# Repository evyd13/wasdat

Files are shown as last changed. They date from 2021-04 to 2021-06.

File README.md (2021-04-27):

# Wasdat and Wasdat Code
The Wasdat and Wasdat Code are are replacement controllers for the WASD V2 and WASD CODE V2B, respectively.

# Use KiCAD nightly!
If you have any trouble opening these files, please download and install the lastest nightly build of KiCAD.

# Read the license!
As with all my projects, please read the license before using these files.

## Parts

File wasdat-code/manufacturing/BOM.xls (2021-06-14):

Wasdat Code BOM
Manufacturer | Manufacturer Part Number | Designator | Qty | Description | Case | SMD ,BGA,LCC,OR TH | Top/Bottom | points (number of contacts the IC has in each board) | Total points (number of contacts per BOM line has) | Comment
Samsung Electro-Mechanics | CL10B104KO8NNNC | C1, C2, C3 | 3 | 100nf capacitor | 0603 | SMD | Bottom
Samsung Electro-Mechanics | CL21A475KAQNNNE | C4 | 1 | 4.7uf capacitor | 0603 | SMD | Bottom
Samsung Electro-Mechanics | CL10A105KP8NNNC | C5 | 1 | 1uf capacitor | 0603 | SMD | Bottom
TLC Electronic | TLC-PSMD050 | F1 | 1 | PTC fuse | 0805 | SMD | Bottom
 |  | H1, H2 | 2 | 2x12 male pin header 2.00mm pitch |  | TH | Bottom
Walsin Tech Corp | WR06X220JTL | R1, R2 | 2 | 22 ohm resistor | 0603 | SMD | Bottom
Walsin Tech Corp | WR06X103JTL | R3, R4, R5 | 2 | 10k ohm resistor | 0603 | SMD | Bottom
Walsin Tech Corp | WR06X102 JTL | R6, R7, R8 | 3 | 1k ohm resistor | 0603 | SMD | Bottom
PANASONIC | ERJP06J750V | R9-R16 | 8 | 75 ohm resistor | 0805 | SMD | Bottom
Microchip Tech | ATMEGA32U4-AU | U1 | 1 | Microcontroller | TQFP-44 | SMD | Bottom
Murata Electronics | CSTNE16M0V530000R0 | X1 | 1 | Resonator 16mhz |  | SMD | Bottom
 | AO3400 | Q1 | 1 | N channel MOSFET | SOT-23 | SMD | Top
Nexperia | 74HC138D | U2 | 1 | Demultiplexer 3-8 line active low | SOIC-16 3.9x9.9 P1.27mm | SMD | Top

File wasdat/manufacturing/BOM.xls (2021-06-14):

Wasdat BOM
Manufacturer | Manufacturer Part Number | Designator | Qty | Description | Case | SMD ,BGA,LCC,OR TH | Top/Bottom | points (number of contacts the IC has in each board) | Total points (number of contacts per BOM line has) | Comment
Samsung Electro-Mechanics | CL10B104KO8NNNC | C1-C4 | 4 | 100nf capacitor | 0603 | SMD | Bottom
Samsung Electro-Mechanics | CL21A475KAQNNNE | C5 | 1 | 4.7uf capacitor | 0805 | SMD | Bottom
Samsung Electro-Mechanics | CL10A105KP8NNNC | C5 | 1 | 1uf capacitor | 0603 | SMD | Bottom
TLC Electronic | TLC-PSMD050 | F1 | 1 | PTC fuse | 0805 | SMD | Bottom
 |  | H1, H2 | 2 | 2x13 male pin header 2.00mm pitch |  | TH | Bottom
Walsin Tech Corp | WR06X220JTL | R1, R2 | 2 | 22 ohm resistor | 0603 | SMD | Bottom
Walsin Tech Corp | WR06X103JTL | R3, R4 | 2 | 10k ohm resistor | 0603 | SMD | Bottom
Walsin Tech Corp | WR06X102 JTL | R5, R6, R7 | 3 | 1k ohm resistor | 0603 | SMD | Bottom
Microchip Tech | ATMEGA32U4-AU | U1 | 1 | Microcontroller | TQFP-44 | SMD | Bottom
Murata Electronics | CSTNE16M0V530000R0 | X1 | 1 | Resonator 16mhz |  | SMD | Bottom
Nexperia | 74HC138D | U2 | 1 | Demultiplexer 3-8 line active low | SOIC-16 3.9x9.9 P1.27mm | SMD | Top

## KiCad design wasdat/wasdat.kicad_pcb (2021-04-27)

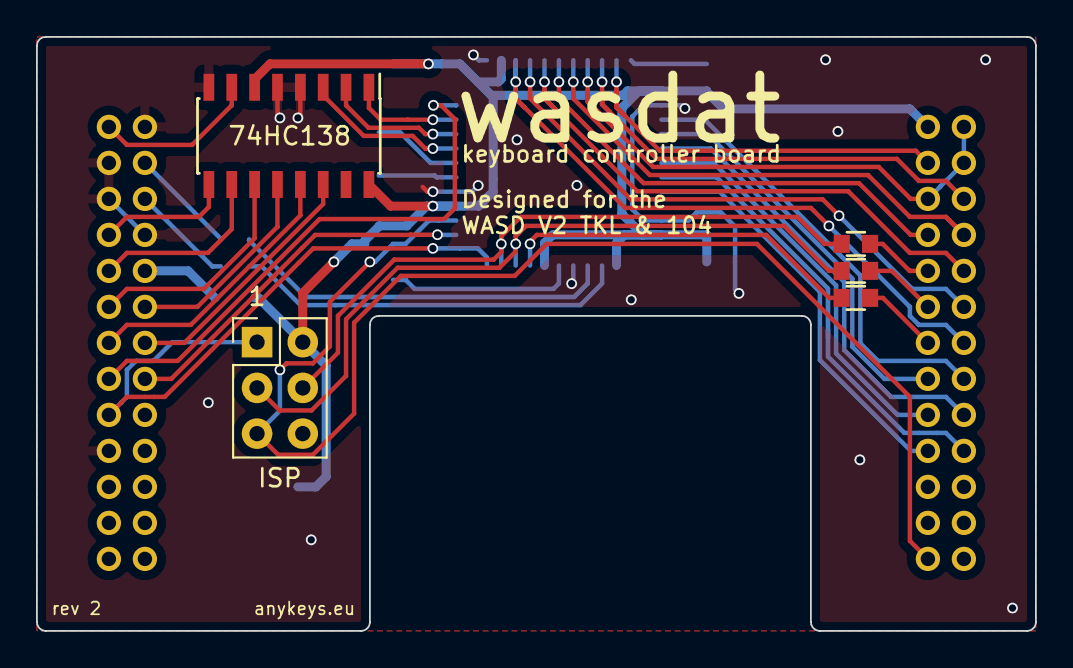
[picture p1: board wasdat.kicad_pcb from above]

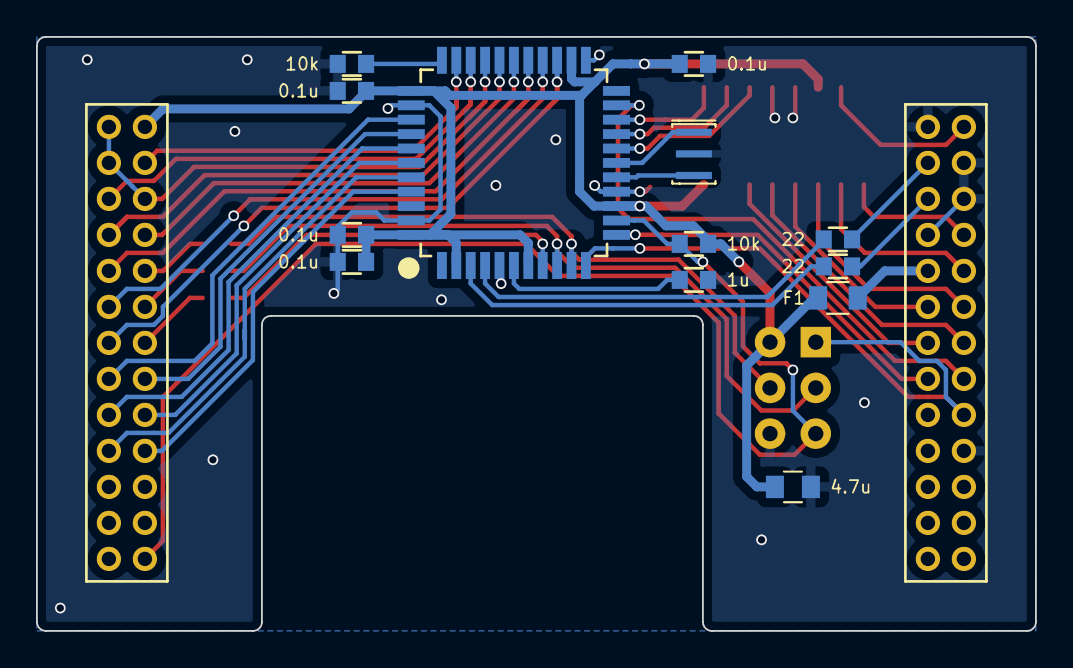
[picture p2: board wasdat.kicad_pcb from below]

Board: 2 copper layers, 55.5 x 33.0 mm, 20 parts (13 on the bottom side), 45 nets.

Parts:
C1, C2, C3, C4: 0.1u; C_0603
C5: 4.7u; C_0805
C6: 1u; C_0603
F1: Polyfuse_Small; R_0805
H1: Left; PinHeader_2x13_P2.00mm_Vertical
H2: Right; PinHeader_2x13_P2.00mm_Vertical
J1: ISP; isp_standard
R1, R2: 22; R_0603
R3, R4: 10k; R_0603
R5, R6, R7: 1k; R_0603
U1: ATmega32U4; ATMEGA32U4
U2: 74HC138; SOIC-16_3.9x9.9mm_P1.27mm
X1: 16mhz; Resonator_SMD_muRata_CSTNExxV-3Pin-p1.2

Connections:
A0: U1.20 ((RXD/INT2)PD2), U2.1 (A0)
A1: U1.19 ((SDA/INT1)PD1), U2.2 (A1)
A2: U1.18 ((OC0B/SCL/INT0)PD0), U2.3 (A2)
D+: H1.4, R1.2
D-: H1.6, R2.2
DIP_1: H2.25, J1.5, R3.2, U1.13 (RESET)
GND: C1.2, C2.2, C3.2, C4.2, C5.2, C6.2, H1.2, H1.3, H1.5, H1.8, H1.19, J1.6, R4.2, U1.5 (UGND), U1.15 (GND), U1.23 (GND), U1.35 (GND), U1.43 (GND), U2.4 (~GL), U2.5 (~G2), U2.8 (GND), X1.3
LED_caps: R7.2, U1.8 ((SS/PCINT0)PB0)
LED_num: J1.4, R5.2, U1.10 ((PDI/MOSI/PCINT2)PB2)
LED_scroll: J1.3, R6.2, U1.9 ((SCLK/PCINT1)PB1)
MISO: H1.17, J1.1, U1.11 ((PDO/MISO/PCINT3)PB3)
unnamed: C6.1, U1.6 (UCAP)
unnamed: F1.2, H1.10
unnamed: H2.9, R5.1
unnamed: H2.11, R6.1
unnamed: H2.13, R7.1
unnamed: R1.1, U1.4 (D+)
unnamed: R2.1, U1.3 (D-)
unnamed: R4.1, U1.33 ((~HWB~)PE2)
unnamed: U1.16 (XTAL2), X1.2
unnamed: U1.17 (XTAL1), X1.1
VCC: C1.1, C2.1, C3.1, C4.1, C5.1, F1.1, H2.1, J1.2, R3.1, U1.2 (UVCC), U1.7 (VBUS), U1.14 (VCC), U1.24 (AVCC), U1.34 (VCC), U1.44 (AVCC), U2.6 (G1), U2.16 (VCC)
col0: H2.3, U1.32 ((ICP3/CLK0/OC4A)PC7)
col1: H2.2, H2.4, H2.5, U1.30 ((ADC13/OC1B/OC4B/PCINT13)PB6)
col2: H2.6, U1.31 ((OC3A/~OC4A~)PC6)
col3: H2.7, U1.28 ((ADC11/PCINT4)PB4)
col4: H2.8, U1.29 ((ADC12/OC1A/~OC4B~/PCINT12)PB5)
col5: H2.10, U1.27 ((T0/OC4D/ADC10)PD7)
col6: H1.1, U2.7 (Y7)
col7: H1.7, U2.9 (Y6)
col8: H1.9, U2.10 (Y5)
col9: H1.11, U2.11 (Y4)
col10: H1.12, U2.12 (Y3)
col11: H1.13, U2.13 (Y2)
col12: H1.14, U2.14 (Y1)
col13: H1.15, U1.21 ((TXD/INT3)PD3)
col14: H1.16, U1.12 ((OC0A/OC1C/~RTS~/PCINT7)PB7)
row0: H2.12, U1.26 ((T1/~OC4D~/ADC9)PD6)
row1: H2.14, U1.25 ((ICP2/ADC8)PD4)
row2: H2.15, U1.37 ((ADC6/TDO)PF6)
row3: H2.16, U1.36 ((ADC7/TDI)PF7)
row4: H2.17, U1.39 ((ADC4/TCK)PF4)
row5: H2.18, U1.38 ((ADC5/TMS)PF5)
row6: H2.19, U1.41 ((ADC0)PF0)
row7: H2.20, U1.40 ((ADC1)PF1)

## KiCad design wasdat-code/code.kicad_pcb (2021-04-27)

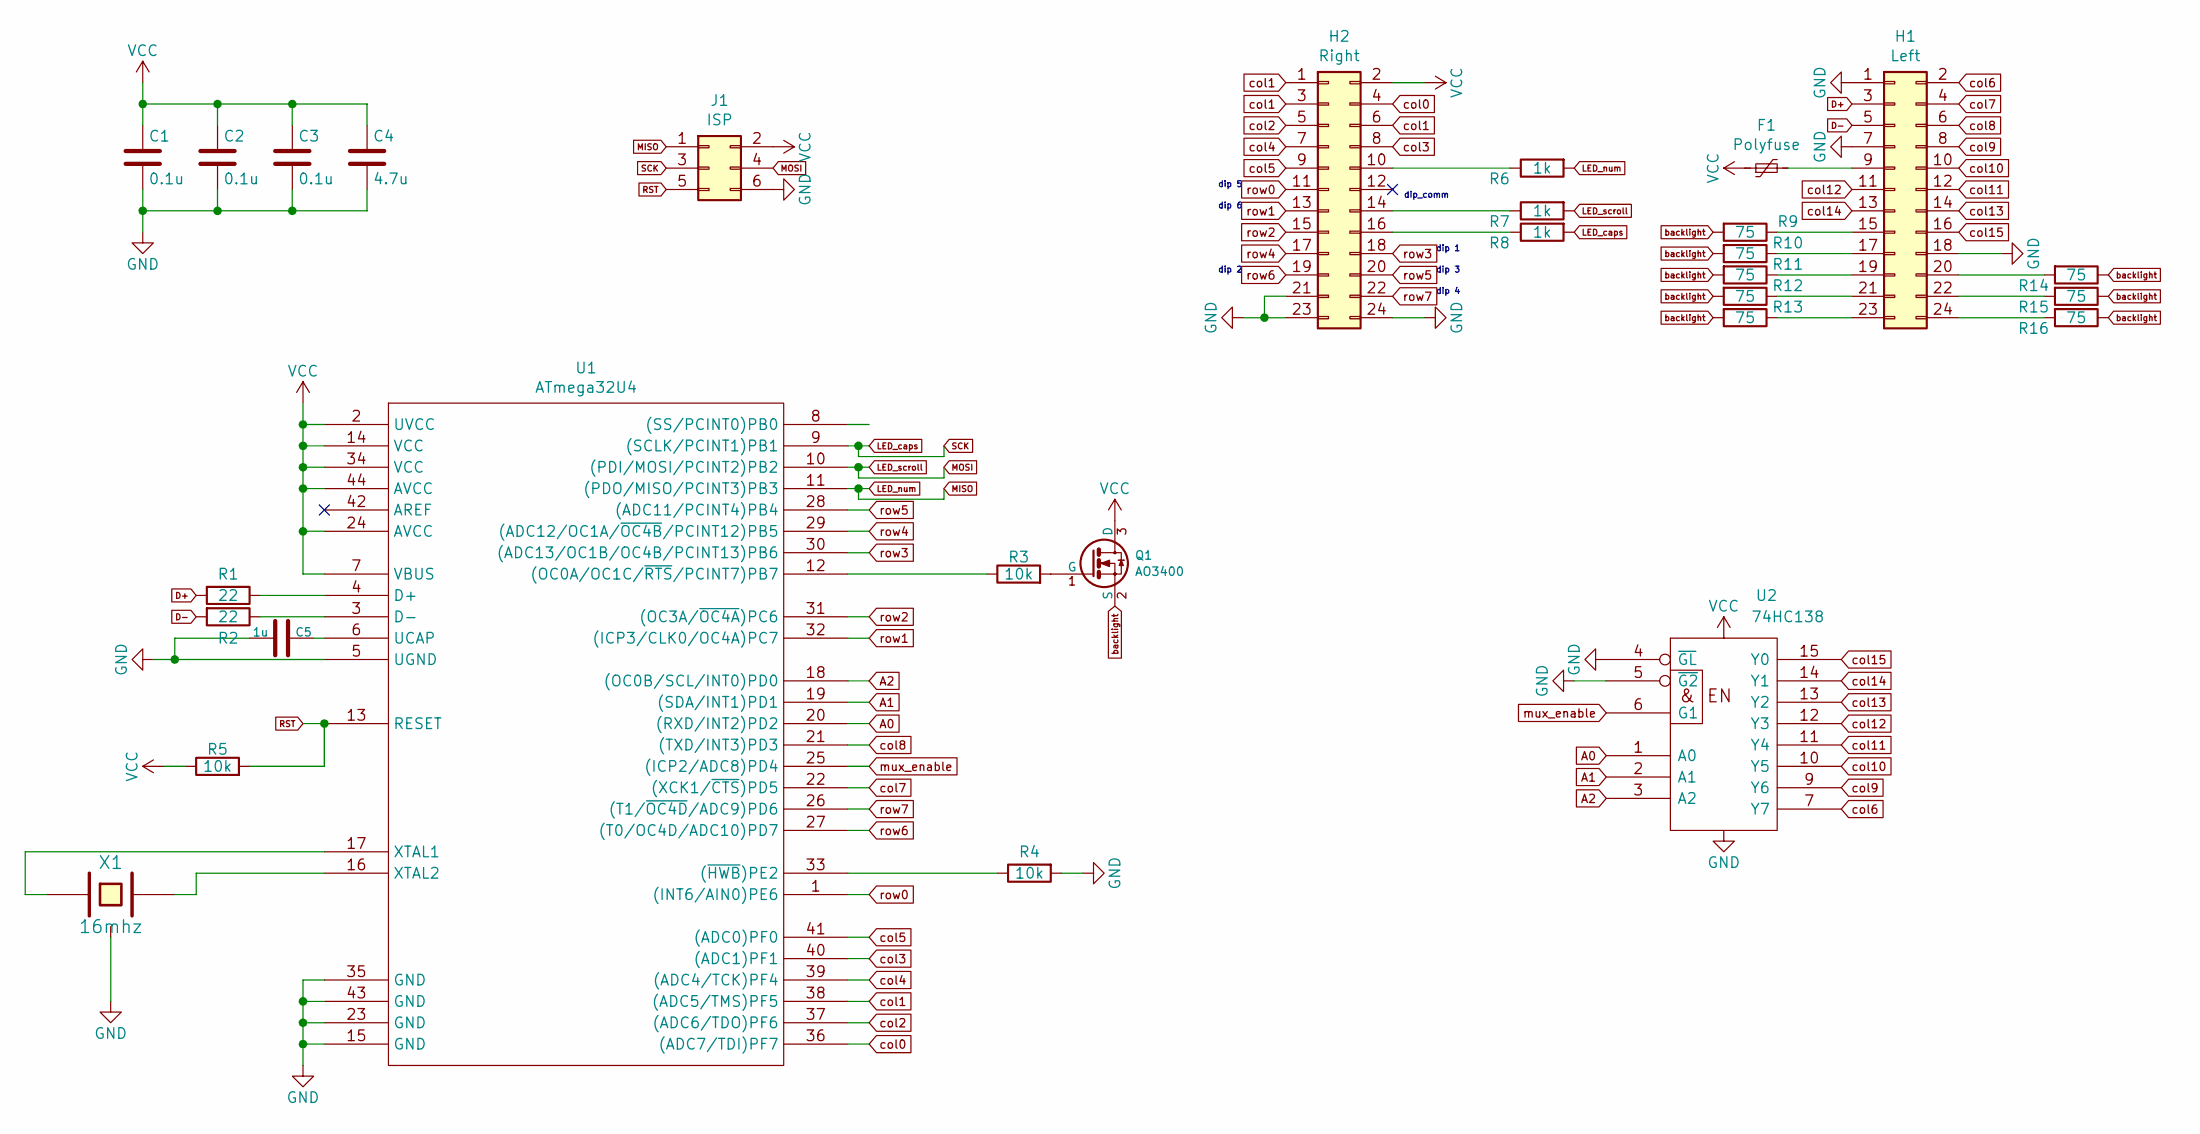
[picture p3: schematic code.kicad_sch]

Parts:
C1, C2, C3: 0.1u; C_0603
C4: 4.7u; C_0805
C5: 1u; C_0603
F1: Polyfuse; R_0805
H1: Left; PinHeader_2x12_P2.00mm_Vertical
H2: Right; PinHeader_2x12_P2.00mm_Vertical
J1: ISP; isp_standard
Q1: AO3400; SOT-23
R1, R2: 22; R_0603
R3, R4, R5: 10k; R_0603
R6, R7, R8: 1k; R_0603
R9, R10, R11, R12, R13, R14, R15, R16: 75; R_0805
U1: ATmega32U4; ATMEGA32U4
U2: 74HC138; SOIC-16_3.9x9.9mm_P1.27mm
X1: 16mhz; Resonator_SMD_muRata_CSTNExxV-3Pin-p1.2

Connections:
A0: U1.20 ((RXD/INT2)PD2), U2.1 (A0)
A1: U1.19 ((SDA/INT1)PD1), U2.2 (A1)
A2: U1.18 ((OC0B/SCL/INT0)PD0), U2.3 (A2)
D+: H1.3, R1.2
D-: H1.5, R2.2
GND: C1.2, C2.2, C3.2, C4.2, C5.2, H1.1, H1.7, H1.18, H2.21, H2.23, H2.24, J1.6, R4.2, U1.5 (UGND), U1.15 (GND), U1.23 (GND), U1.35 (GND), U1.43 (GND), U2.4 (~GL), U2.5 (~G2), U2.8 (GND), X1.3
LED_caps: J1.3, R8.2, U1.9 ((SCLK/PCINT1)PB1)
LED_num: J1.1, R6.2, U1.11 ((PDO/MISO/PCINT3)PB3)
LED_scroll: J1.4, R7.2, U1.10 ((PDI/MOSI/PCINT2)PB2)
unnamed: F1.2, H1.9
unnamed: H1.15, R9.1
unnamed: H1.17, R10.1
unnamed: H1.19, R11.1
unnamed: H1.20, R14.2
unnamed: H1.21, R12.1
unnamed: H1.22, R15.2
unnamed: H1.23, R13.1
unnamed: H1.24, R16.2
unnamed: H2.10, R6.1
unnamed: H2.14, R7.1
unnamed: H2.16, R8.1
unnamed: Q1.1 (G), R3.2
unnamed: R2.1, U1.3 (D-)
unnamed: R3.1, U1.12 ((OC0A/OC1C/~RTS~/PCINT7)PB7)
unnamed: R4.1, U1.33 ((~HWB~)PE2)
unnamed: U1.16 (XTAL2), X1.2
unnamed: U1.17 (XTAL1), X1.1
RST: J1.5, R5.2, U1.13 (RESET)
VCC: C1.1, C2.1, C3.1, C4.1, F1.1, H2.2, J1.2, Q1.3 (D), R5.1, U1.2 (UVCC), U1.7 (VBUS), U1.14 (VCC), U1.24 (AVCC), U1.34 (VCC), U1.44 (AVCC), U2.16 (VCC)
backlight: Q1.2 (S), R9.2, R10.2, R11.2, R12.2, R13.2, R14.1, R15.1, R16.1
col0: H2.4, U1.36 ((ADC7/TDI)PF7)
col1: H2.1, H2.3, H2.6, U1.38 ((ADC5/TMS)PF5)
col2: H2.5, U1.37 ((ADC6/TDO)PF6)
col3: H2.8, U1.40 ((ADC1)PF1)
col4: H2.7, U1.39 ((ADC4/TCK)PF4)
col5: H2.9, U1.41 ((ADC0)PF0)
col6: H1.2, U2.7 (Y7)
col7: H1.4, U1.22 ((XCK1/~CTS~)PD5)
col8: H1.6, U1.21 ((TXD/INT3)PD3)
col9: H1.8, U2.9 (Y6)
col10: H1.10, U2.10 (Y5)
col11: H1.12, U2.11 (Y4)
col12: H1.11, U2.12 (Y3)
col13: H1.14, U2.13 (Y2)
col14: H1.13, U2.14 (Y1)
col15: H1.16, U2.15 (Y0)
mux_enable: U1.25 ((ICP2/ADC8)PD4), U2.6 (G1)
row0: H2.11, U1.1 ((INT6/AIN0)PE6)
row1: H2.13, U1.32 ((ICP3/CLK0/OC4A)PC7)
row2: H2.15, U1.31 ((OC3A/~OC4A~)PC6)
row3: H2.18, U1.30 ((ADC13/OC1B/OC4B/PCINT13)PB6)
row4: H2.17, U1.29 ((ADC12/OC1A/~OC4B~/PCINT12)PB5)
row5: H2.20, U1.28 ((ADC11/PCINT4)PB4)
row6: H2.19, U1.27 ((T0/OC4D/ADC10)PD7)
row7: H2.22, U1.26 ((T1/~OC4D~/ADC9)PD6)

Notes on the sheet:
dip 5
dip 6
dip 2
dip_comm
dip 1
dip 3
dip 4

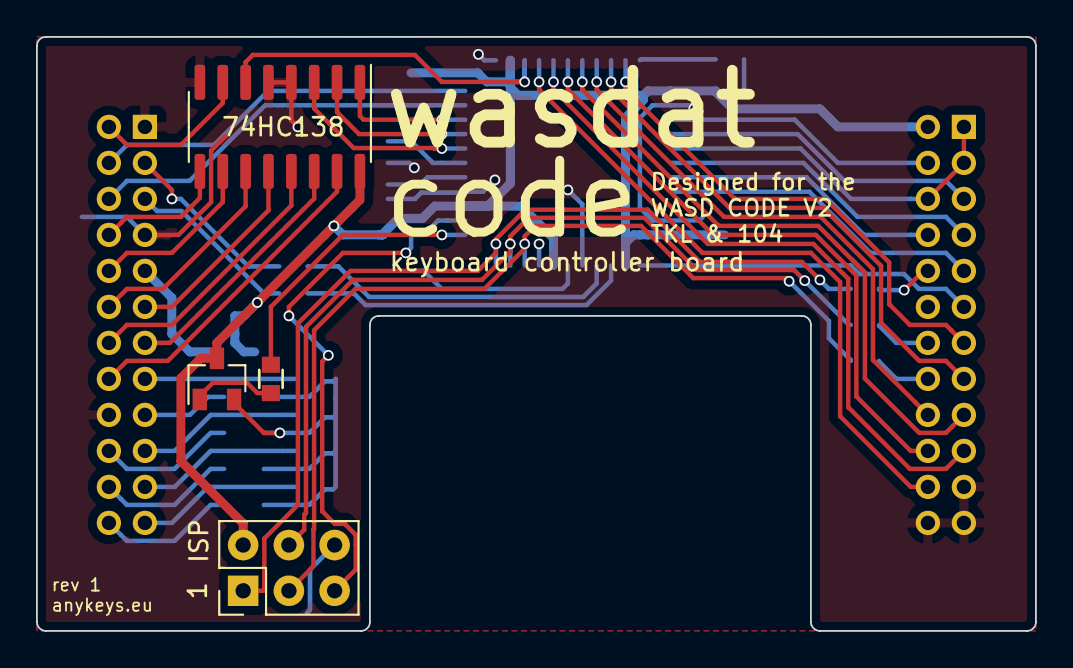
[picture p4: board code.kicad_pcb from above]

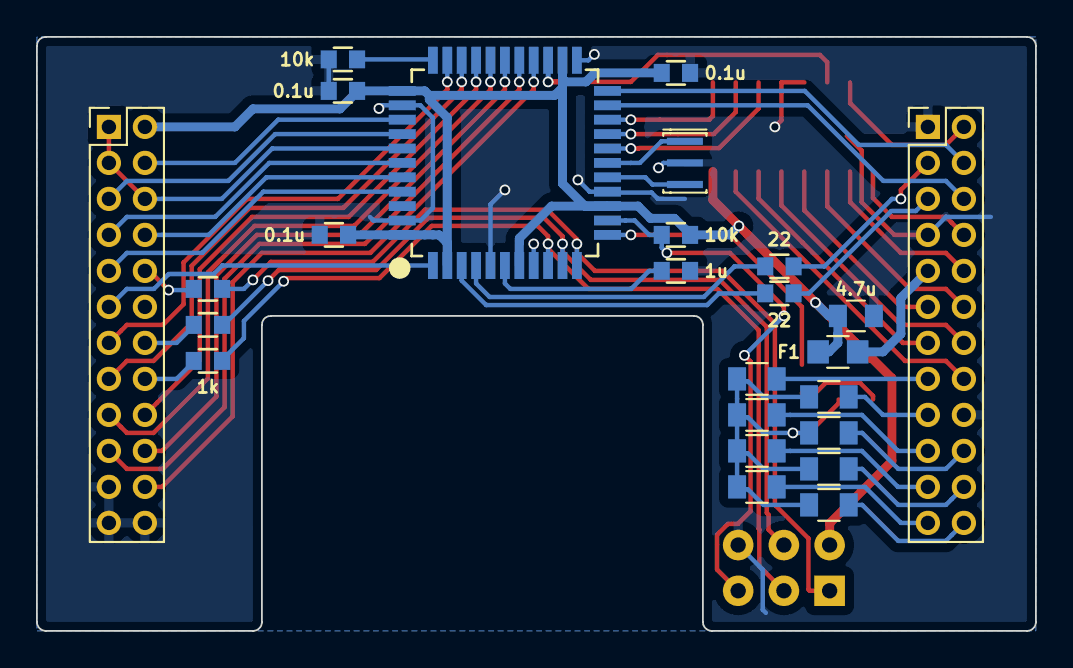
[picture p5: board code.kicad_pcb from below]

Board: 2 copper layers, 55.5 x 33.0 mm, 29 parts (25 on the bottom side), 55 nets.

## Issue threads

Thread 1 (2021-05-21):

Inconsistency about Atmega32U4 package/footprint

t-8ch, 2021-05-21:
In the BOM.xls files the case for the microprocessor is listed as `QFN-44`.
According to the datasheet from Atmel (and digikey) these have a 7mm x 7mm footprint.
The schema files however consistently use a 10mm x 10mm `TQFP-44` package.

evyd13, 2021-06-14:
Thanks! Has been corrected.

Closed 2021-06-14.

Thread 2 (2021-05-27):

Cannot open the project or PCB files using KiCad 5.1.10 from May 2021

springcomp, 2021-05-27:
When trying to open any of the files, I get some syntax errors.
The most easy error to understand is when I try to open the .pcb file.

It tells me I need a more recent version of KiCad, past 28th February 2021.

I’m running this version :
https://www.kicad.org/blog/2021/05/KiCad-5.1.10-Release/

From Windows 10.

springcomp, 2021-05-28:
Can indeed open using nightly build as.suggested in readme.

Closed 2021-05-28.

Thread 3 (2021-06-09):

wasdat: BOM.xls: wrong amount of 100nf capacitors

t-8ch, 2021-06-09:
The BOM for the wasdat lists "3" in the quantity column for 100nf capacitors.
Actually 4 are needed.
(As can also be seen in the "designator" column of the BOM)

evyd13, 2021-06-14:
Thanks! Has been corrected.

Closed 2021-06-14.
